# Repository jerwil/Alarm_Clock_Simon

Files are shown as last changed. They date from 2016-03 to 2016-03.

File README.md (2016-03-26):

# Memory Game Alarm Clock

A device to make waking up easier by challenging your mind in the morning.

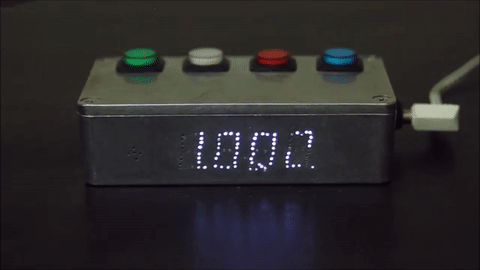
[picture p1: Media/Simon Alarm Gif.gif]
Alarm Clock Animation


See the blog post here: [http://www.jeremyadamwilson.com/memory-game-alarm-clock/](http://www.jeremyadamwilson.com/memory-game-alarm-clock/)

## Features

* Requires a memory game to be beaten to turn off alarm
* All functions of alarm clock are controlled by 4 memory game buttons
* Buttons light up whenever pressed for feedback
* Intuitive alarm and time setting
* Adjustable brightness
* Adjustable difficulty
* 12/24 hour time display modes

## Demo Video

See all the features in the [demo video](https://www.youtube.com/watch?v=Q9e83-DTT6o).

## How to Use

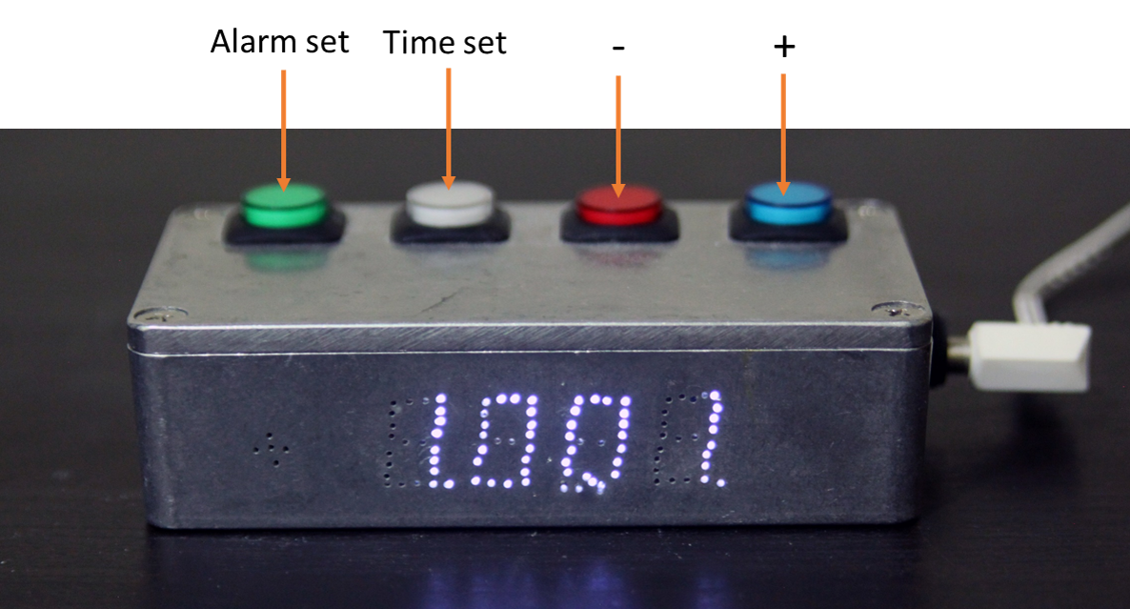
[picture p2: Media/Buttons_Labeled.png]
Buttons labeled


* The leftmost button controls the alarm time, while the next button to the right controls the current time
* The right two buttons are for + and -
* Without holding down any other button, + and - control the display brightness.
* With the alarm set botton held, + and - change the alarm time
* With the time button held, + and - change the current time
* With the leftmost two buttons held, + and - change the difficulty level
* The alarm set button is double-pressed to toggle the alarm on or off

## Requirements

### Subsystems

This project brought together a lot of smaller projects I had worked on in the past. The below sections describe the various subsystems that all came together to make this project.

*Real Time Clock*

The DS 1307 real time clock requires a crystal, resistors, and a 3V battery. It communicates to the ATMega328 by the I²C protocol.I started out using a breakout board kit for prototyping, but for the final design all the support hardware was put onto the alarm clock circuit board.

*ATMega238, buttons, lights, and memory game*

The ability to create my own smart device based on the ATMega328 without an Arduino was learned during my [Arduino independence project](http://www.jeremyadamwilson.com/arduino-independence-simon-game/). Using the same support hardware, I was able to build onto that project to form the complete alarm clock circuit board.

The logic for the memory game was pulled from my [Arduino Simon](https://github.com/jerwil/Simon_Etch) project.

*LED Display*

The circuit board design for the LED display was pulled from my [MAX7219 7 segment LED driver board project](https://github.com/jerwil/MAX7219_Hello_World).

### Hardware

* ATMega328
* DS 1307 Real Time Clock
* Coin battery holder
* 220Ω resistors
* 10kΩ resistors
* 100Ω resistor
* 10 mF capacitors
* 16 mHz oscillator for ATMega328
* Buzzer
* Buttons with built-in LEDs
* Power jack
* Body/housing
* Male and female headers for stacking design

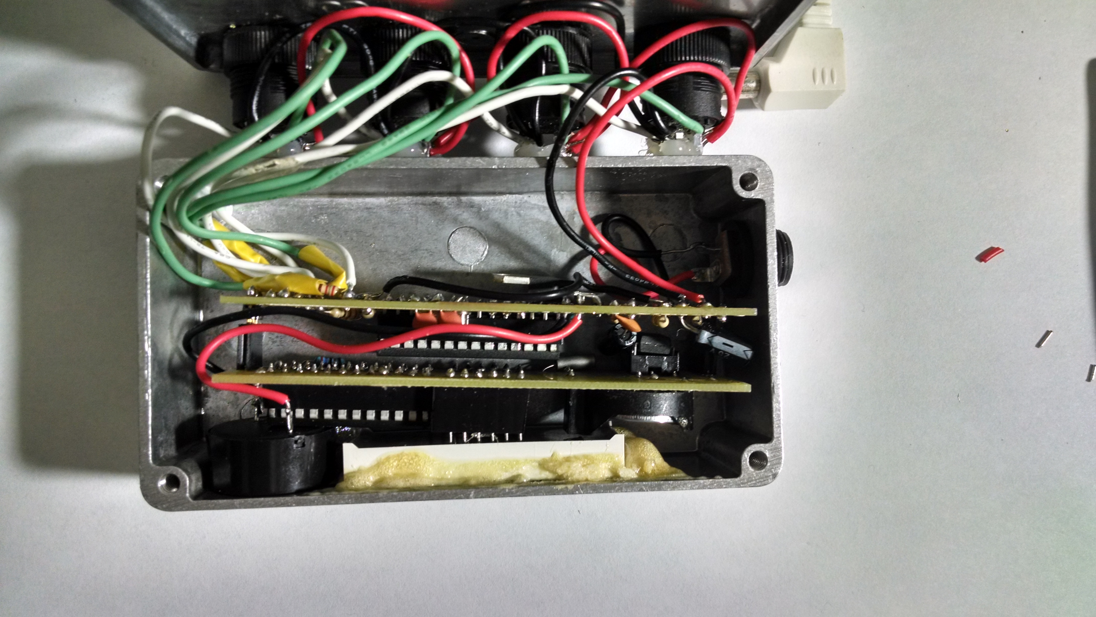
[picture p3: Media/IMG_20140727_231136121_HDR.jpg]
Fully assembled alarm clock


### Schematics

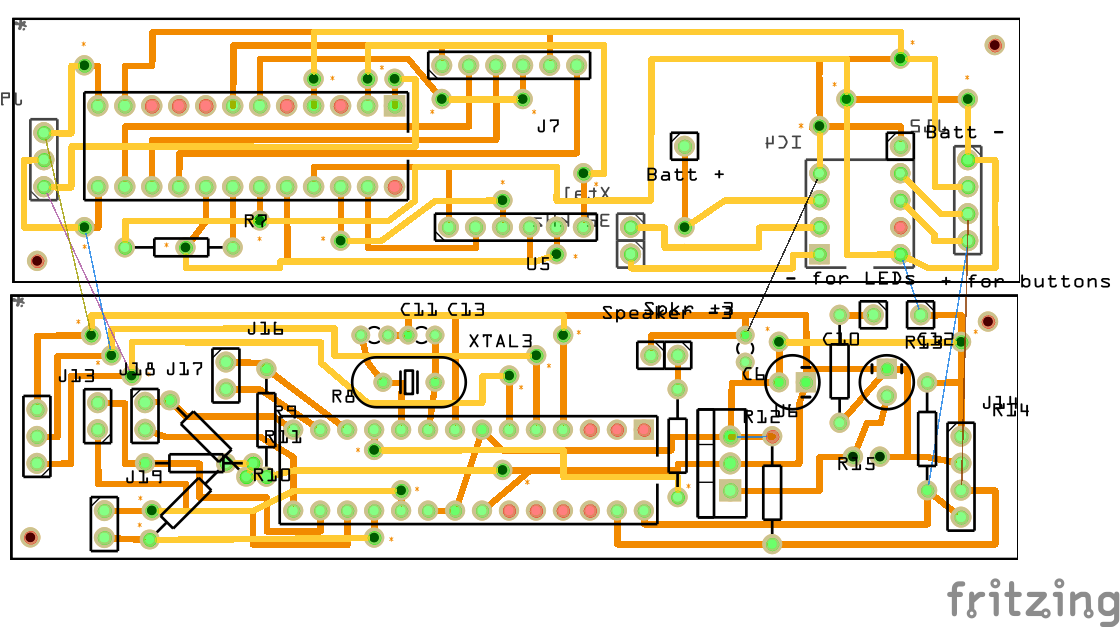
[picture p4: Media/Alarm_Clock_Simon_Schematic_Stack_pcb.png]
Alarm Clock Schematic


See the included Fritzing diagram (.fzz file) for details.

### License

<br /><span xmlns:dct="http://purl.org/dc/terms/" property="dct:title">Memory Game Alarm Clock</span> by <a xmlns:cc="http://creativecommons.org/ns#" href="http://www.JeremyAdamWilson.com">Jeremy Wilson</a> is licensed under a <a rel="license" href="http://creativecommons.org/licenses/by-nc/4.0/">Creative Commons Attribution-NonCommercial 4.0 International License</a>.

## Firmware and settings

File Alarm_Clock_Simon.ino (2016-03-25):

// Arduino memory game alarm clock by Jeremy Wilson
// Date and time functions using a DS1307 RTC connected via I2C and Wire lib
 
#include <Wire.h>
#include "RTClib.h"
#include <LedControl.h> // For more info see http://www.wayoda.org/arduino/ledcontrol/index.html
 
RTC_DS1307 RTC;

LedControl mydisplay = LedControl(4, 3, 2, 1); // *** Changed for board design simplicity ***

int adjust_amount = 60;    // how many seconds to adjust the time by in seconds
int multiplier = 1; // This mutliplier is used to change to hour adjustment if needed

unsigned long currentTime;
unsigned long loopTime;

int current_count;
char* mode = "time_disp";
double alarm = 28800; // Alarm default in seconds (8:00 AM)
int alarm_array[6];
int current_time_array[6];
int old_second = 0; //This is used for the tick mechanism
int now_second = 0;
int unixtime_int = 0;
int display_array[6];
int time_format = 12;
boolean button_hi = false;
int button_state = 0;
int button_counter = 0; // This is used to detect how long the button is held for
int timeout = 0; // Time out for not pushing the button for a while
int blink = 1; // This is used for blinking numbers while adjusting time
double second_timer[1] = {0}; // This is used to keep track of the timer used to tick for each second
double half_second_timer[1] = {0}; // This is used to keep track of the timer used to tick for each second
double time_set_timer[1] = {0}; // This is used to keep track of the timer used for time setting
double button_hold_timer[1] = {0}; // This is used to keep track of the timer used for time setting
int time_set_tick = 200;
int PM = 0; // This is the indicator that time is in PM

// _____ Arrays to store button state: _____ //

int button1_press_initiate[1] = {0}; 
int button1_press_completed[1] = {0}; 
int button2_press_initiate[1] = {0}; 
int button2_press_completed[1] = {0}; 
int button3_press_initiate[1] = {0}; 
int button3_press_completed[1] = {0}; 
int button4_press_initiate[1] = {0}; 
int button4_press_completed[1] = {0}; 

int button_pushed = 0; // This is the indicator that the button was pushed and released
int alarm_tone = 1000; // This is the frequency for the alarm buzzer
int speakerPin = 5; // This is the pin used by the alarm buzzer
int alarmLEDPin = 2; // This is the pin used to indicate if the alarm is on
boolean alarm_on = false;
unsigned long double_click_timeout;
int click_once = 0; // This integer is used to store the fact that we have one click and are looking for the second to occur before the delay
int double_clicked = 0; // This tells us if a double click occured.
int tone_happening = 0;

boolean Alarm_DP = false; //Indicate if the alarm decimal point should be lit
boolean PM_DP = false; //Indicate if the PM decimal point should be lit
boolean DP = false; //A general decimal point variable
int LCD_brightness = 7;


// _______ Hardware Constants: ________ //

int button1 = 6;
int button2 = 8;
int button3 = 10;
int button4 = 12;

int led1 = 7;
int led2 = 9;
int led3 = 11;
int led4 = 13;

int button_states[4] = {0,0,0,0};
int button_presses[4] = {0,0,0,0};

// _______ Constants for Simon portion: ______ //

int gamestate = 0;
int waitingforinput = 0;
int currentlevel = 1; // This is the level (also the number of button presses to pass to next level)
long randnum = 0; //initialize long variable for random number from 0-100.
int randnumint = 0; //initialize random integer for loop. Will be from 1-4 later.
int butwait = 500; //amount of time to wait for next button input (ghetto de-bounce)
int ledtime = 500; //amount of time each LED flashes for when button is pressed
int numlevels = 11; //number of levels + 1 until the game is won (numlevels-1 = sequence length)
int pinandtone = 0; //This integer is used when the sequence is displayed
int correct = 0; //This variable must be 1 in order to go to the next level
int speedfactor = 5; //This is the final speed of the lights and sounds for the last level. This increases as more games are won
int leddelay = 200; //Initializing time for LED. This will decrease as the level increases
const int tones[] = {1915, 1700, 1519, 1432, 2700}; // The last tone is the fail tone
const int ledpins[] = {7, 9, 11, 13}; //This is the LED pin format for the simon code
const int buttonpins[] = {6, 8, 10, 12}; //This is the button pin format for the simon code
int lastbutton_states[] = {0,0,0,0}; 
int buttonPushCounter[] = {0,0,0,0}; 
int simon_timeout = 0;

void setup () {
  
randomSeed(analogRead(A0)); //By taking the random seed from an open (unwired) analog channel, it is as close as you can get to a true random number
  

  
    pinMode (speakerPin, OUTPUT);
    pinMode (alarmLEDPin, OUTPUT);
    pinMode(button1, INPUT);
    pinMode(button2, INPUT);
    pinMode(button3, INPUT);
    pinMode(button4, INPUT);
    pinMode(led1, OUTPUT);
    pinMode(led2, OUTPUT);	
    pinMode(led3, OUTPUT);	
    pinMode(led4, OUTPUT);		

    Serial.begin(57600);
    Wire.begin();
    RTC.begin();
	DateTime now = RTC.now();
	int now_second = now.second();
	old_second = now_second;
    //DateTime now = RTC.now();
	
 
  if (! RTC.isrunning()) {
    Serial.println("RTC is NOT running!");
  }
  
    // following line sets the RTC to the date & time this sketch was compiled
    // RTC.adjust(DateTime(__DATE__, __TIME__));
    
mydisplay.shutdown(0, false);  // turns on display
mydisplay.setIntensity(0, LCD_brightness); // 15 = brightest

}


void printtime(DateTime time){ // This function mainly used for debugging purposes
    Serial.print(" time: ");
    Serial.print(time.year(), DEC);
    Serial.print('/');
    Serial.print(time.month(), DEC);
    Serial.print('/');
    Serial.print(time.day(), DEC);
    Serial.print(' ');
    Serial.print(time.hour(), DEC);
    Serial.print(':');
    Serial.print(time.minute(), DEC);
    Serial.print(':');
    Serial.print(time.second(), DEC);
    Serial.println();
    Serial.print("mode = ");    
    Serial.print(mode);
    Serial.println();  
}

void time_to_ints(DateTime time, int time_array[6]){
    int year_int, month_int, day_int, hour_int, minute_int, second_int;
    year_int = time.year();
    month_int = time.month();
    day_int = time.day();
    hour_int = time.hour();
    minute_int = time.minute();
    second_int = time.second();
    time_array[0] = year_int;
    time_array[1] = month_int;
    time_array[2] = day_int;
    time_array[3] = hour_int;
    time_array[4] = minute_int;
    time_array[5] =  second_int;
}

double time_to_double(DateTime time){
    double year_int, month_int, day_int, hour_int, minute_int, second_int;
    year_int = time.year();
    month_int = time.month();
    day_int = time.day();
    hour_int = time.hour();
    minute_int = time.minute();
    second_int = time.second();
    double seconds = hour_int*3600+minute_int*60+second_int;
    return seconds;
}

void print_time_array_separated(int time_array[6]){
  Serial.println();
  Serial.print("Hours: ");
  Serial.println(time_array[3]);
  Serial.print("Minutes: ");
  Serial.println(time_array[4]);
  Serial.print("Seconds: ");
  Serial.println(time_array[5]);
  
}

int tick(int delay, double timekeeper[1]){
currentTime = millis();
if(currentTime >= (timekeeper[0] + delay)){
	timekeeper[0] = currentTime;
	return 1;
  }
else {return 0;}
}

void secs_to_hms(double secs_in, int time_array[6]){
    double hours = floor(secs_in/3600);
    double minutes = floor(((secs_in - hours*3600)/60));
    double seconds = floor((secs_in - hours*3600 - minutes*60));
    int hour_int = hours;
    int minute_int = minutes;
    int second_int = seconds;
    time_array[3] = hour_int;
    time_array[4] = minute_int;
    time_array[5] = second_int;
}

double time_array_to_secs(int time_array[6]){
    return time_array[3]*60*60 + time_array[4]*60 + time_array[5];
}

void time_array_to_digit_array(int time_array[6], int digit_array[6]){
  int hours = time_array[3];
  int minutes = time_array[4];
  int seconds = time_array[5];
  PM = 0; // AM until proven PM
  
  if (time_format == 12){
	if (hours == 12){PM = 1;}
	else if (hours > 12) {
		hours -= 12;
		PM = 1;
	}
	else if (hours == 0){
	hours = 12;
	PM = 0;
	}
  }
  
  if (hours < 10 && hours > 0){
    digit_array[0] = 10; // 10 will be the designation for not displaying anything
    digit_array[1] = hours;
  }
  else {
    digit_array[0] = hours/10;
    digit_array[1] = hours%10;
  }
  if (minutes < 10){
  digit_array[2] = 0; // 10 will be the designation for not displaying anything
  digit_array[3] = minutes;
  }
  else {
    digit_array[2] = minutes/10;
    digit_array[3] = minutes%10;
  }
  if (time_format == 24){PM = 0;} // The PM LED is not needed in 24 hour time format

}

int button_press (int button_indicator, int button_press_initiated[1], int button_press_complete[1]){
	if (button_indicator == 0 && button_press_initiated[0] == 1) {
	button_press_complete[0] = 1;
	Serial.print("Button press complete");
	Serial.println();
	button_press_initiated[0] = 0;
	}
	else if (button_indicator == 1){
	button_press_initiated[0] = 1;
	button_press_complete[0] = 0;
	}
	else {button_press_complete[0] = 0;}
return button_press_complete[0];
}

void buzz(int tone) {
    digitalWrite(speakerPin, HIGH);
    delayMicroseconds(tone);
    digitalWrite(speakerPin, LOW);
    delayMicroseconds(tone);
}

void buttoncheck(int button_states[4]){
//  for (int i=0;i<4;i++){button_states[i]=0;}
  if(digitalRead(button1)){button_states[0] = 1;}
  else {button_states[0] = 0;}
  if(digitalRead(button2)){button_states[1] = 1;}
  else {button_states[1] = 0;}
  if(digitalRead(button3)){button_states[2] = 1;}
  else {button_states[2] = 0;}
  if(digitalRead(button4)){button_states[3] = 1;}
  else {button_states[3] = 0;}
}

int double_click(int delay, int button_to_check){
int double_click_complete;
	if (button_to_check == 1){
		if (click_once == 1 && millis() <= double_click_timeout + delay){
		double_click_complete = 1;
		Serial.print("Second click of couble click");
		Serial.println();
		}
		else if (click_once == 0) {
		click_once = 1;
		double_click_complete = 0;
		double_click_timeout = millis();
		Serial.print("First click of couble click");
		Serial.println();
		}
	}
	if (button_to_check == 0 && millis() >= double_click_timeout + delay){
	click_once = 0;
	double_click_complete = 0;
	}
return double_click_complete;
}

void check_button_presses()
{
  button_presses[0] = button_press (button_states[0], button1_press_initiate, button1_press_completed); 
  button_presses[1] = button_press (button_states[1], button2_press_initiate, button2_press_completed); 
  button_presses[2] = button_press (button_states[2], button3_press_initiate, button3_press_completed); 
  button_presses[3] = button_press (button_states[3], button4_press_initiate, button4_press_completed);  
}

boolean compare_array(int a,int b,int c,int d, int array_to_compare[4]){
return(a == array_to_compare[0] && b == array_to_compare[1] && c == array_to_compare[2] && d == array_to_compare[3]);
}

void LEDs_with_buttons(int button_status[4]){
 if (button_status[0] == 1){digitalWrite(led1, HIGH);}
 else{digitalWrite(led1, LOW);}
 if (button_status[1] == 1){digitalWrite(led2, HIGH);}
 else{digitalWrite(led2, LOW);}
 if (button_status[2] == 1){digitalWrite(led3, HIGH);}
 else{digitalWrite(led3, LOW);}
 if (button_status[3] == 1){digitalWrite(led4, HIGH);}
 else{digitalWrite(led4, LOW);}
}

void update_screen(int array_to_display[4]){
  for (int digit = 0; digit < 4; digit++)  {
   if (digit == 3){DP = PM_DP;} // For the last digit, light up decimal point if time is PM
   else if (digit == 0){DP = Alarm_DP;} // For the first digit, light up decimal point if the alarm is on
   else {DP = false;}
 
   if (array_to_display[digit] == 10){          // This is the convention for a blank digit
    mydisplay.setChar(0,3-digit,' ', DP); // This is how you print a blank digit (as a space character)
   }
   else {mydisplay.setDigit(0, 3-digit, array_to_display[digit], DP);} 
 }  
 mydisplay.setIntensity(0, LCD_brightness); // 15 = brightest 
}

// Functions for Simon portion:

void playTone(int tone, int duration) {
  tone_happening = 1;
  for (long dur = 0; dur < duration * 1000L; dur += tone * 2) {
    digitalWrite(speakerPin, HIGH);
    delayMicroseconds(tone);
    digitalWrite(speakerPin, LOW);
    delayMicroseconds(tone);
//    Serial.print("Playing tone:");
//    Serial.print(tone);
//    Serial.print("    Duration is:");
//    Serial.println(dur);
    tone_happening = 1;
  }
  tone_happening = 0;
}

// _____________ PROGRAM STARTS HERE: _____________//

void loop () {

if (PM == 1){PM_DP = true;}
else{PM_DP = false;}



if(mode == "time_disp"){ // This is current time mode

// Grab time from real time clock (RTC) and convert into format used by this program

  DateTime now = RTC.now();
  time_to_ints(now, current_time_array);
  time_array_to_digit_array(current_time_array, display_array);
 
 // The following checks the alarm condition:
 
  if (alarm == time_to_double(now) && alarm_on == true){
  mode = "alarm_sound";
  }
 
  buttoncheck(button_states); // Checks all 4 buttons and updates the array

  LEDs_with_buttons(button_states);

  check_button_presses();

  currentTime = millis();


// _____________ Setting Display Brightness: _____________//

if(compare_array(0,0,0,1,button_presses) && compare_array(0,0,0,0,button_states) && LCD_brightness < 15){LCD_brightness ++;} // If the 4th button is pressed and no others are, increase brightness up to max
if(compare_array(0,0,1,0,button_presses) && compare_array(0,0,0,0,button_states) && LCD_brightness >= 1){LCD_brightness --;} // If the 3rd button is pressed and no others are, decrease brightness down to min
if(compare_array(0,0,1,0,button_presses) && compare_array(0,0,0,0,button_states) && LCD_brightness == 0){mydisplay.shutdown(0, true);}  // turns off display below min brightness
if (LCD_brightness >= 1){mydisplay.shutdown(0, false);}

// _____________ Setting Current Time: _____________//

if (button_states[1])
  {
  if (tick(500, half_second_timer) == 1)
    {
      if (blink == 0){blink = 1;}
      else if (blink == 1){blink = 0;}  
    }
  if (button_counter >= 8){time_set_tick = 5;} // As the button is held down longer, the time adjustment speed increases
  else if (button_counter >= 5){time_set_tick = 10;}
  else if (button_counter >= 3){time_set_tick = 50;}
  else {time_set_tick = 200;}
  time_array_to_digit_array(current_time_array, display_array); 
  now = RTC.now();
    if (compare_array(0,1,1,0,button_states))
    {
      if (tick(time_set_tick, time_set_timer) == 1)
      {
      DateTime then(now.unixtime() - adjust_amount*multiplier);
      RTC.adjust(then);
      now = RTC.now();
      }
      if (tick(1000,button_hold_timer) == 1){button_counter += 1;}
      blink = 1;
    }
    else if (compare_array(0,1,0,1,button_states)){
      if (tick(time_set_tick, time_set_timer) == 1)
      {
      DateTime then(now.unixtime() + adjust_amount*multiplier);
      RTC.adjust(then);
      now = RTC.now();
      }
      if (tick(1000,button_hold_timer) == 1){button_counter += 1;}
      blink = 1;
    }
    else { button_counter = 0;}
  time_array_to_digit_array(current_time_array, display_array);
  if (blink == 0 && button_counter == 0){
    for(int k=0; k<4; k++){display_array[k] = 10;}
  }
  }


// _____________ Setting Alarm: _____________//

if (button_states[0]){
  if (tick(500, half_second_timer) == 1)
  {
    if (blink == 0){blink = 1;}
    else if (blink == 1){blink = 0;}  
  }
  if (button_counter >= 8){time_set_tick = 5;} // As the button is held down longer, the time adjustment speed increases
  else if (button_counter >= 5){time_set_tick = 10;}
  else if (button_counter >= 3){time_set_tick = 50;}
  else {time_set_tick = 200;}
  secs_to_hms(alarm, alarm_array);
  if (compare_array(1,0,1,0,button_states))
    {
    if (tick(1000,button_hold_timer) == 1){button_counter += 1;}
    if (tick(time_set_tick, time_set_timer) == 1){alarm -= adjust_amount*multiplier;}
    blink = 1;
    }
  else if (compare_array(1,0,0,1,button_states))
    {
    if (tick(1000,button_hold_timer) == 1){button_counter += 1;}
    if (tick(time_set_tick, time_set_timer) == 1){alarm += adjust_amount*multiplier;}
    blink = 1;
    }
  else { button_counter = 0;}  
  if (alarm > 86400) {alarm -= 86400;} //Alarm will roll over
  if (alarm < 0) {alarm += 86400;}
  time_array_to_digit_array(alarm_array, display_array);
  if (blink == 0 && button_counter == 0){
    for(int k=0; k<4; k++){display_array[k] = 10;}
  }
}

// _____________ Toggling Alarm: _____________//
// The alarm is toggled on and off by double-clicking the first button
if (alarm_on == true){Alarm_DP = true;} // This indicates if the alarm is on (Alarm_DP means alarm decimal point)
else {Alarm_DP = false;}

double_clicked = double_click(250, button_presses[0]);
if (double_clicked == 1){
  alarm_on = !alarm_on;
  click_once = 0;
  double_clicked = 0;
}

// _____________ Toggling 12/24 hour mode: _____________//
// The clock is switched between 12 and 24 hour mode by double-clicking the 2nd button

double_clicked = double_click(250, button_presses[1]);
if (double_clicked == 1){
  if (time_format == 12){time_format = 24;}
  else if (time_format == 24){time_format = 12;}
  click_once = 0;
  double_clicked = 0;
}


// _____________ Setting Difficulty: _____________//
// This allows the user to choose the sequence length required to turn off the alarm. This is done by holding down the first two buttons then using the right two buttons as + and -.
// To keep it challenging, a sequence of 5 is the minimum, but 16 is the max (10 is really hard anyway!)
if (button_states[0] && button_states[1]){
  if (tick(500, half_second_timer) == 1)
  {
    if (blink == 0){blink = 1;}
    else if (blink == 1){blink = 0;}  
  }
  if(compare_array(0,0,0,1,button_presses) && numlevels < 17) // If the 4th button is pressed and no others are, increase number of levels up to max of 16 (5 in sequence)
  {
    numlevels ++; 
    blink = 1;
  } 
  if(compare_array(0,0,1,0,button_presses) && numlevels > 6) // If the 3rd button is pressed and no others are, decrease number of levels down to min of 6 (5 in sequence)
  {
    numlevels --;
    blink = 1;
  }
  display_array[0] = 10; // First two digits are blank
  display_array[1] = 10;
  if ((numlevels-1) < 10){
  display_array[2] = 0;
  display_array[3] = numlevels-1;
  }
  else {
    display_array[2] = (numlevels-1)/10;
    display_array[3] = (numlevels-1)%10;
  }
  if (blink == 0 && button_counter == 0){for(int k=0; k<4; k++){display_array[k] = 10;}}
}

// _____________ Voluntary Simon Mode: _____________//
// This will allow the user to play Simon on-demand by pushing all 4 buttons at once when the alarm is off
if (compare_array(1,1,1,1,button_states) && alarm_on == false){
mode = "alarm_sound";
for(int k=0; k<4; k++){digitalWrite(ledpins[k], LOW);}
double_clicked = 0;
click_once = 0;
delay(500);
}

update_screen(display_array); // Every cycle of time display mode updates the screen with whatever is in the display_array

}

// _______ End of time display mode ______//

// _____________ Alarm Mode: _____________//
 
if(mode == "alarm_sound"){ // This is alarm mode
  
//The following clears out then initializes both arrays for new games  
  
int numarray[numlevels];
int userarray[numlevels];
int i;

if (gamestate == 0){
for (i = 0; i < numlevels; i = i + 1) {
   numarray[i]=0;
   userarray[i]=0;
  randnum = random(1,100);
    if (randnum <= 25) {
      randnumint = 0;
    }
    if (randnum > 25){
    randnumint = 1;
  }
    if (randnum > 50){
    randnumint = 2;
  }
    if (randnum > 75){
    randnumint = 3;
  }
  numarray[i]=randnumint;
//  Serial.println(numarray[i]);
}
if (i == numlevels){
 gamestate = 1; 
}
}


//The following will show the user the current sequence
if (waitingforinput == 0){
 delay (200);
i = 0;
for (i = 0; i < currentlevel; i= i + 1){
  leddelay = ledtime;
      pinandtone = numarray[i];
      digitalWrite(ledpins[pinandtone], HIGH);
      playTone(tones[pinandtone], leddelay);
      digitalWrite(ledpins[pinandtone], LOW);
      delay(100/speedfactor);
    }
    waitingforinput = 1;
}
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

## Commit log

2013-10-19 First commit - trying to get controls working
    Button press code currently not working with button states as vector.
    Need to de-bug. Also need to remove or modify some states.
    [Alarm_Clock_Simon.ino]
2013-10-19 Got double-clicking to work
    It's pretty ghetto, each button has its own array to store button press
    initiation and completion. I should look into consolidating this
    somehow.
2013-10-19 Got alarm set working
    Currently alarm time will go up or down every half second. Need to add
    logic to adjust multiplier based upon time button is held down
2013-10-20 Cleaning up code
    Moving the different available actions, and giving each a commented
    heading. Next I need to make a function to compare arrays so specific
    button combos can be used in if() statements.
2013-10-20 Time set acceleration in progress
    I have a basic framework for the time to change faster the longer you
    hold the button. It is only working for decrementing time, so I need to
    figure out why that is.
2013-10-20 Time set acceleration works for time and alarm
    The problem was a conflict between two 1 second timers. I commented out
    the 1 second timer that prints information for now. Need to find
    long-term solution that allows for these timers to coexist.
    [Alarm_Clock_Simon.ino]
2013-10-22 Fixed alarm set sped bug
    Also improved brightness adjustment to be more robust. Screen turns off
    completely at brightness of 0, and turns on for any brightness 1 or
    above.
    [Alarm_Clock_Simon.ino]
2013-10-26 Added Simon code
    Code is currently not working properly, the system hangs after simon
    starts.
    [Alarm_Clock_Simon.ino]
2013-11-01 First commit, adding code from alarm to simon
    Trying to find which piece of code messes up the program a few lines at
    a time. Currently added initial variables and pin assignments.
2013-11-02 Base functionality of Simon alarm clock works!
    The basic concept of the alarm clock is now working! I now need to make
    the alarm more persistent, I need to make it so the user chooses the
    first button in the sequence, and I need to look into capacitive touch
    before I lock down the hardware.
2013-11-02 Major advancements to PCB layout
    Still need to deal with capacitors on display, center display, and
    figure out how to wire buttons
    [Alarm_Clock_Simon_Schematic.fzz]
2013-11-05 A basic version of annoyance is in place for alarm
    Basically it resets every time the counter hits 5 seconds with no
    action. Also created a new fritzing file for the two chips to be stacked
    on each other for final product.
    [Alarm_Clock_Simon_Schematic.fzz, Alarm_Clock_Simon_Schematic_Stack.fzz]
2013-11-05 Alarm mode works as it should
    This method is a bit messy. I need to clean it up & look into making the
    button chosen the first button of the new sequence. This is a stretch
    goal at this point, as I need to focus on hardware design to complete
    before 11/15 deadline.
2013-11-07 Further developing layout
    Currently no location for ATtiny85 (for battery backed-up annoyance) and
    nowhere for buttons to plug in.
    [Alarm_Clock_Simon_Schematic_Stack.fzz]
2013-11-07 Starting to add buttons
    Still need a place for the speaker, and I need to figure out how to
    handle the resistors for the buttons.
    [Alarm_Clock_Simon_Schematic_Stack.fzz]
2013-11-09 First complete design
    There are currently no resistors going to the LEDs. This makes the LEDs
    very bright, and it can potentially damage them. There is currently no
    space for these resistors. I also need to add a 5V and 0V line for the
    buttons/lights to share.
    [Alarm_Clock_Simon_Schematic_Stack.fzz]
2013-11-09 Swapped battery and DS1307 sides
    This solved an interference problem after the boards are stacked. I also
    added the necessary resistors for the DS1307 onto the main board.
    [Alarm_Clock_Simon_Schematic_Stack.fzz]
2013-11-09 Performed design rules check and fixed
    Resistor pads are close to other traces. Otherwise the design is sound
    from a design rules standpoint. I fill do a final check of the whole
    design & breadboard.
    [Alarm_Clock_Simon_Schematic_Stack.fzz]
2013-11-09 Marked each via with an asterisk
    I still need to do a final check of all connections & compare to
    physical bread board
    [Alarm_Clock_Simon_Schematic_Stack.fzz]
2014-06-23 Fixed flipped timing chip
    Accidentally had timing chip on wrong side of board
    [Alarm_Clock_Simon_Schematic_Stack.fzz]
2014-06-23 Still need to fix ATMega board
    [Alarm_Clock_Simon_Schematic_Stack.fzz]
2014-06-23 Fixed ATMega board
    Should be ready for production
    [Alarm_Clock_Simon_Schematic_Stack.fzz]
2014-06-24 Fixed switched wires on RTC
    [Alarm_Clock_Simon_Schematic_Stack.fzz]
2014-06-24 Fixed hole overlapping trace
    [Alarm_Clock_Simon_Schematic_Stack.fzz]
2014-07-03 Swapped LedControl pins to match design
    [Alarm_Clock_Simon_Schematic_Stack_Production.fzz]
2014-07-03 Reviewed the design - ok to produce
    Compared design with current breadboard connections on working alpha
    version.
    [Alarm_Clock_Simon_Schematic_Stack.fzz]
2014-07-21 Updated resistor values to their actuals
    [Alarm_Clock_Simon_Schematic_Stack.fzz]
2014-07-27 Fixed time update bug
    Also made default alarm time 8:00 AM. Two issues closed
    [Alarm_Clock_Simon.ino]
2014-07-28 Added toggle between 12/24 hour format
    Double click 2nd button to toggle. Also lowered the double-click time,
    requiring the user to make both button presses within 1/4 of a second
    instead of a whole second as before. This reduces accidental
    double-clicks
2014-07-28 Made setting times blink & added escape from Simon
    If the player is in voluntary simon mode and doesn't press anything for
    5 seconds, the game will return to time display mode and reset the game
    parameters
    [Alarm_Clock_Simon.ino]
2016-03-25 Re-organized repository
    Put old files in archive folder
    [Alarm_Clock_Simon_Schematic.fzz, Alarm_Clock_Simon_Schematic_Stack_Production.fzz]
